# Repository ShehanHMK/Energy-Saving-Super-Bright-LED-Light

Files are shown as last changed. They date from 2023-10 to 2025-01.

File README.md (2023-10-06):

# Energy-Saving-Super-Bright-LED-Light

This project was done as a semester project under *_Electronic Design Realization_* module in Electronic and Telecommunication department. Main objective of this project was manufacture a consumer product for the market.   

## ***Project Description***

The product is Super bright - 18W Ceiling LED light with adjustable brightness and color temperature using an IR remote. The user can easily mount the light on their ceiling and control it using a remote with friendly user interface. In addition to brightness and color adjustability, it has lot of features and functions which makes more convenient for users.

----

## ***Features and Functions***

- Power - 18W
- Color Temperature - 5000K to 10000K
- Remote type - IR Remote , Works within 7 meter range
- Operating Voltage - 230V 50/60 Hz AC

### Functions of the remote

- Continuous Brighness and color temperature adjustability
- Enabling timers to **auto turn off**.
- Direct 25% / %50 brightness enabling option
- Special pre defined color modes - _Warm white, Cool white and Daylight white_

----

## ***Functionality of the Light***

This light consists two main parts. First one is the LED light panel and the second part is the LED driver. LED Driver controls the current to the LED light panel and maintains a constant current.
Led light is powered up from main 230V AC supply.At first, Main voltage is converted into 24V DC voltage using a 24V 1A switching mode power supply (SMPS). Then the current is divided into 4 channels and fed into mosfet based constant current sources. Those 4 current sources keep the current through themselves constant always and provide to LED panel. An IR reciever recieves the signals from IR remote and  **ATTINY 85** microcontroller decodes those signal to provide the control signals for the current sources to activate the required function.   

### _LED Driver_

Consist of 4 mosfet based constant current sources. Current limit of those sources are controlled by control signals from attiny85 microcontroller.


---


-----

### _LED Light Panel_

4 Led channels with 7 series high power 1W led in each string are mounted on a PCB with aluminium as the base material. It provides a good thermal conductivity and acts a heat sink to each of those 1W small led bulbs.


---


### Schematic designs and PCB layouts were designed using _Altium Designer_ software and printed fron [JLC PCB](https://jlcpcb.com/) .

-----

## ***Enclosure***

An Enclosure to mount the LED panel and another enclosure to place the SMPS and driver circuit were designed using _Solidworks 3D_ software and manufactured using 3D printing.


---


-----

## ***Assembled LED Light***



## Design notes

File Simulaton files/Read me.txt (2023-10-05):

Open the LED_lamp proteus file and upload the IR_remote_with_pwm.ino.hex file to ATtiny85.

Click Run

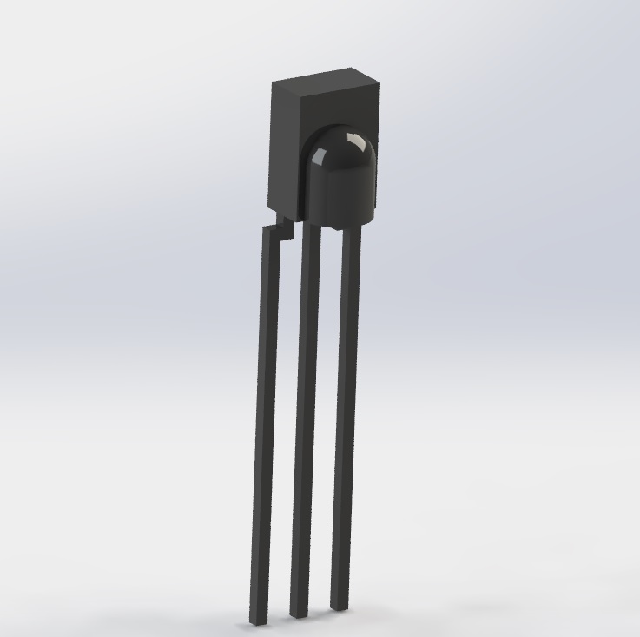
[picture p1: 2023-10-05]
Enclosure designs/LED Light Enclosure/IR Receiver.JPG

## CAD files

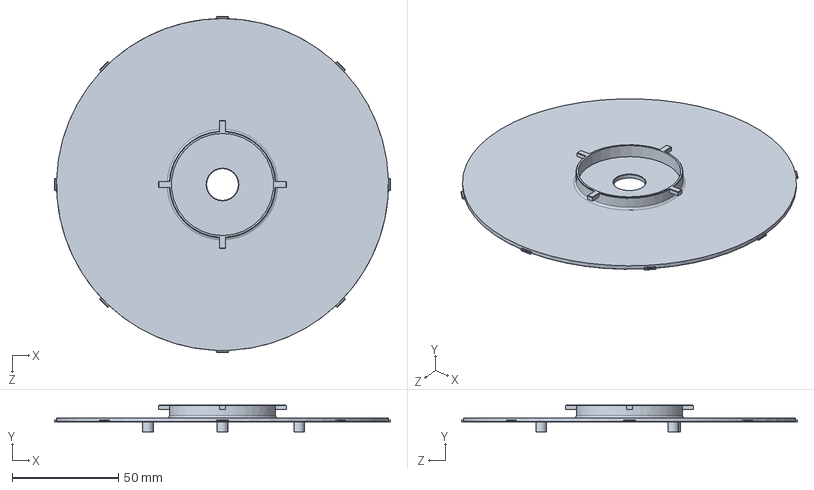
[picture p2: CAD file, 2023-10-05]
Enclosure designs/LED Light Enclosure/light main body.SLDPRT
157.9 x 12.6 x 157.9 mm

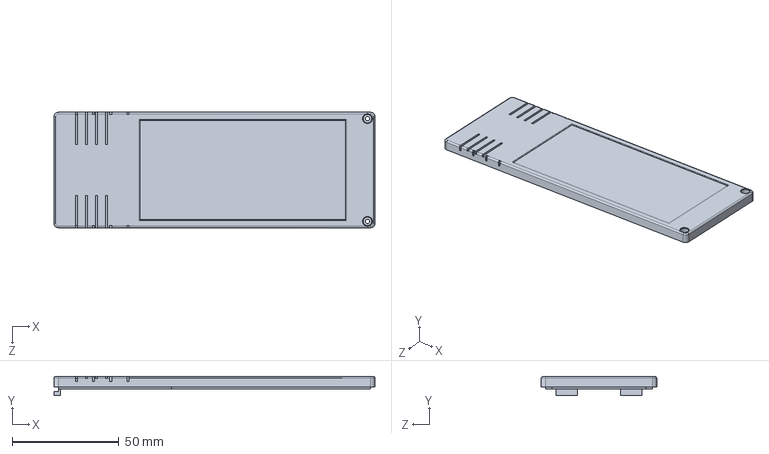
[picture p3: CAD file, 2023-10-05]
Enclosure designs/LED Driver Enclosure/driver cover.SLDPRT
150.0 x 9.00 x 54.0 mm

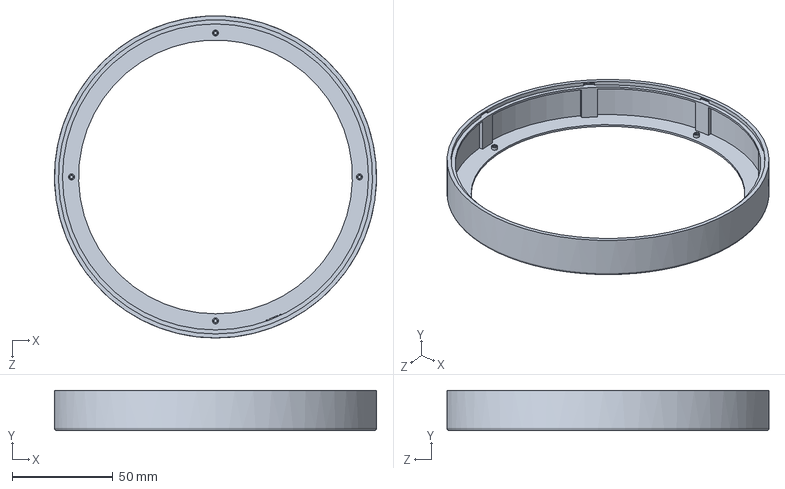
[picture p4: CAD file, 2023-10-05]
Enclosure designs/LED Light Enclosure/light body.SLDPRT
160.0 x 20.0 x 159.9 mm

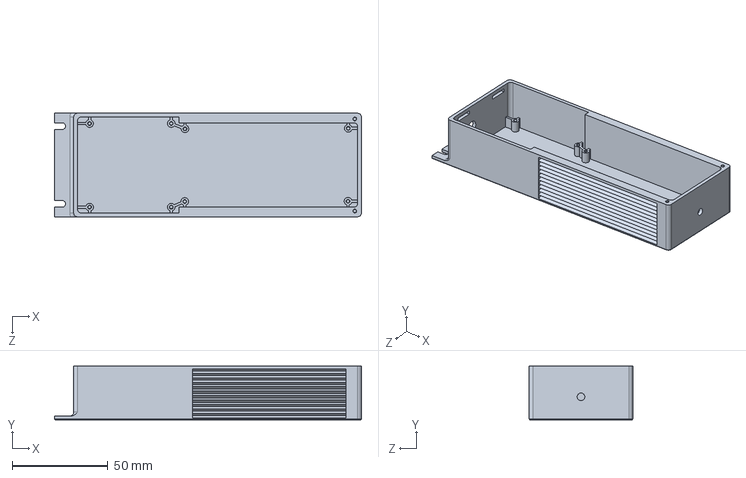
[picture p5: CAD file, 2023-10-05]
Enclosure designs/LED Driver Enclosure/Driver body.SLDPRT
160.0 x 28.0 x 54.0 mm

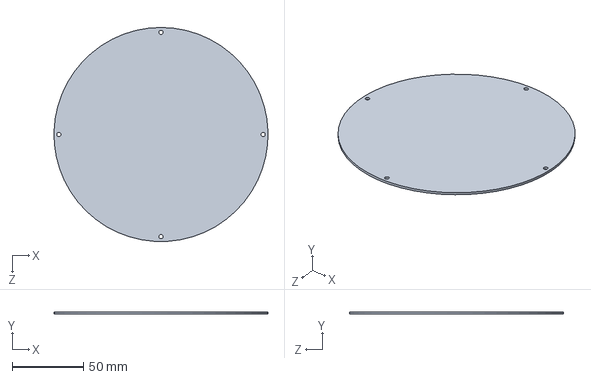
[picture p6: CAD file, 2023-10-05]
Enclosure designs/LED Light Enclosure/light transparent front cover.SLDPRT
149.9 x 1.50 x 150.0 mm

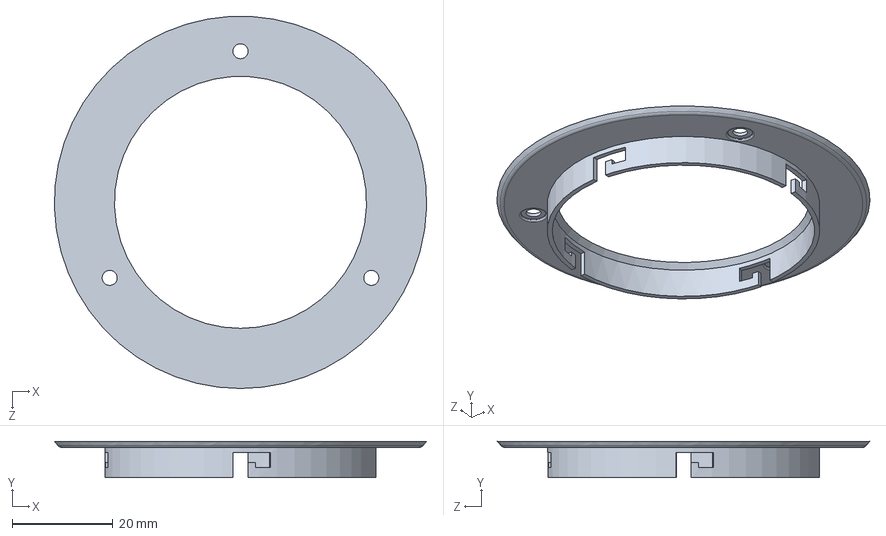
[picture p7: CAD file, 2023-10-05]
Enclosure designs/LED Light Enclosure/socket.SLDPRT
73.9 x 7.20 x 73.9 mm

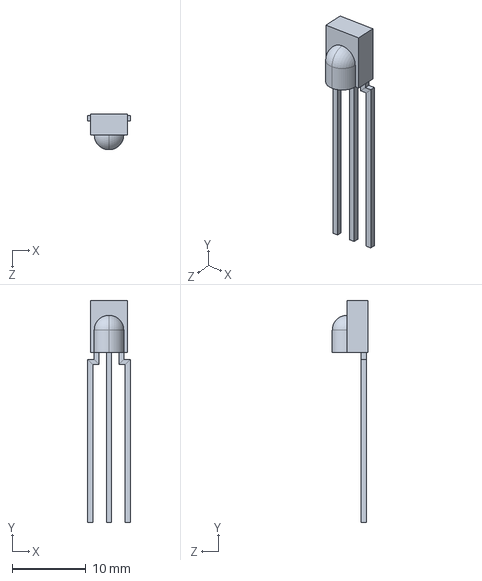
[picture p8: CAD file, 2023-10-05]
Enclosure designs/LED Light Enclosure/IR Receiver.STEP
5.78 x 30.0 x 4.80 mm

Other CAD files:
Enclosure designs/LED Light Enclosure/IR Receiver.SLDPRT

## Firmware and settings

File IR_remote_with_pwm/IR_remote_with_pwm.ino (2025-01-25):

#define IR_RECEIVE_PIN 2
#include "TinyIRReceiver.hpp"

#define pwmCoolpin 4
#define pwmWarmpin 1   // previous ( In the PCB ) 1 , 0 in the simulation   

#define  powerON 69 
#define  ReadMode 71             
#define  bright_up  9          // 25 in simulation         
#define  bright_dowm  7        // 22 in simulation       
#define  temp_up 25            // 21 in simulation
#define  temp_dowm 64          // 7 in simulation 
#define  brightness25 12
#define  brightness50 24
#define  brightness75 94
#define  Select_warm  8
#define  Select_Daylight 28
#define  Select_cool  90
#define  Timer10 66
#define  Timer30 82
#define  Timer60 74  


const byte REMOTE_ADDRESS = 0;
byte Timer_Value=0;
unsigned long timer_enabled_time=0;
bool TIMER_ENABLED = false;
bool isON = false;   

short int cool_value;
short int  warm_value;
float temp=0;
short int brightness=0;

volatile struct TinyIRReceiverCallbackDataStruct sCallbackData;

void setup() {
 
  initPCIInterruptForTinyReceiver();
  pinMode(pwmCoolpin,OUTPUT);
  pinMode(pwmWarmpin,OUTPUT);
  

  digitalWrite(pwmCoolpin,LOW);
  digitalWrite(pwmWarmpin,LOW);
}

void loop() {

  if(TIMER_ENABLED && (( millis()-timer_enabled_time ) >= Timer_Value*60*1000)){
    brightness=0;
    isON=false;
  }
  
  if(sCallbackData.justWritten){
    
    sCallbackData.justWritten=false;
    
    if(sCallbackData.Address==REMOTE_ADDRESS){

      if(sCallbackData.Command==powerON && sCallbackData.Flags==0){
        TIMER_ENABLED=false;

        if(brightness>0){
          brightness=0;
          isON=false;
          cool_value=(0.5+temp)*brightness;
          warm_value=(0.5-temp)*brightness;
              
          analogWrite(pwmWarmpin,warm_value);
          analogWrite(pwmCoolpin,cool_value);

          delay(500);
          
        }
        else{
          brightness=255;
          isON=true;

          cool_value=(0.5+temp)*brightness;
          warm_value=(0.5-temp)*brightness;
              
          analogWrite(pwmWarmpin,warm_value);
          analogWrite(pwmCoolpin,cool_value);

          delay(500);
          
        }
      }

      if(isON && sCallbackData.Command!=powerON){

        if(sCallbackData.Command==bright_up){
          if(brightness<255){
            brightness=brightness+17;
          }
        }
        else if(sCallbackData.Command==bright_dowm){
          if(brightness>0){
            brightness=brightness-17;
          }
        }
        else if(sCallbackData.Command==temp_up){
          if(temp<0.5){
            temp=temp+0.1;
          }
        }
        else if(sCallbackData.Command==temp_dowm){
          if(temp>-0.5){
            temp=temp-0.1;
          }
        }
        else if(sCallbackData.Command==brightness25 && sCallbackData.Flags==0){
          brightness=64;
        }
        else if(sCallbackData.Command==brightness50 && sCallbackData.Flags==0){
          brightness=127;
        }
        else if(sCallbackData.Command==brightness75 && sCallbackData.Flags==0){
          brightness=191;
        }
        else if(sCallbackData.Command==Select_warm && sCallbackData.Flags==0){
          temp=-0.5;
        }
        else if(sCallbackData.Command==Select_cool && sCallbackData.Flags==0){
          temp=0.5;
        }
        else if(sCallbackData.Command==Select_Daylight && sCallbackData.Flags==0){
          temp=0;
        }
        else if((sCallbackData.Command==Timer10 || sCallbackData.Command==Timer30 ||sCallbackData.Command==Timer60) && sCallbackData.Flags==0){
          TIMER_ENABLED=true;
          timer_enabled_time=millis();

          switch (sCallbackData.Command){
            case Timer10:
              Timer_Value=10;
              break;
            case Timer30:
              Timer_Value=30;
              break;
            case Timer60:
              Timer_Value=60;
              break;
          }
        }
        else if(sCallbackData.Command==ReadMode && sCallbackData.Flags==0){
          temp=-0.4;
          brightness=210;
        }

        cool_value=(0.5+temp)*brightness;
        warm_value=(0.5-temp)*brightness;
                  
        analogWrite(pwmWarmpin,warm_value);
        analogWrite(pwmCoolpin,cool_value);

        delay(10);

        
      }
      
      
    }
    
      
  }

  
  
}

void handleReceivedTinyIRData(uint8_t aAddress, uint8_t aCommand, uint8_t aFlags){
  sCallbackData.justWritten=true;
  sCallbackData.Address=aAddress;
  sCallbackData.Command=aCommand;
  sCallbackData.Flags=aFlags;
}
